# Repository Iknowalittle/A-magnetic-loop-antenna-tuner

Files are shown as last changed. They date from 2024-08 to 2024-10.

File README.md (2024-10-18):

This is a simple proto type magnetic loop antenna automatically tune project.
The code can be edit and build with Adunino.

There are somethings that I tried to implemented: 
  1) This stepper motor controller, after some search , finnaly I choose the motor driver chip TMC2209, It has the special function named "sensorless stall detection", which is definitely good 
for Vaccume capacitor because we have no good method to add the physical position limit sensor.
  2) The SWR meter. I use SI5351 act as the signal source and 2 AD8307 chips act as the forard and revese power meter to calculate the SWR.

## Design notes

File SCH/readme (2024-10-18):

open it wirh EAGLE 7.2 or later.
simple double side PCB

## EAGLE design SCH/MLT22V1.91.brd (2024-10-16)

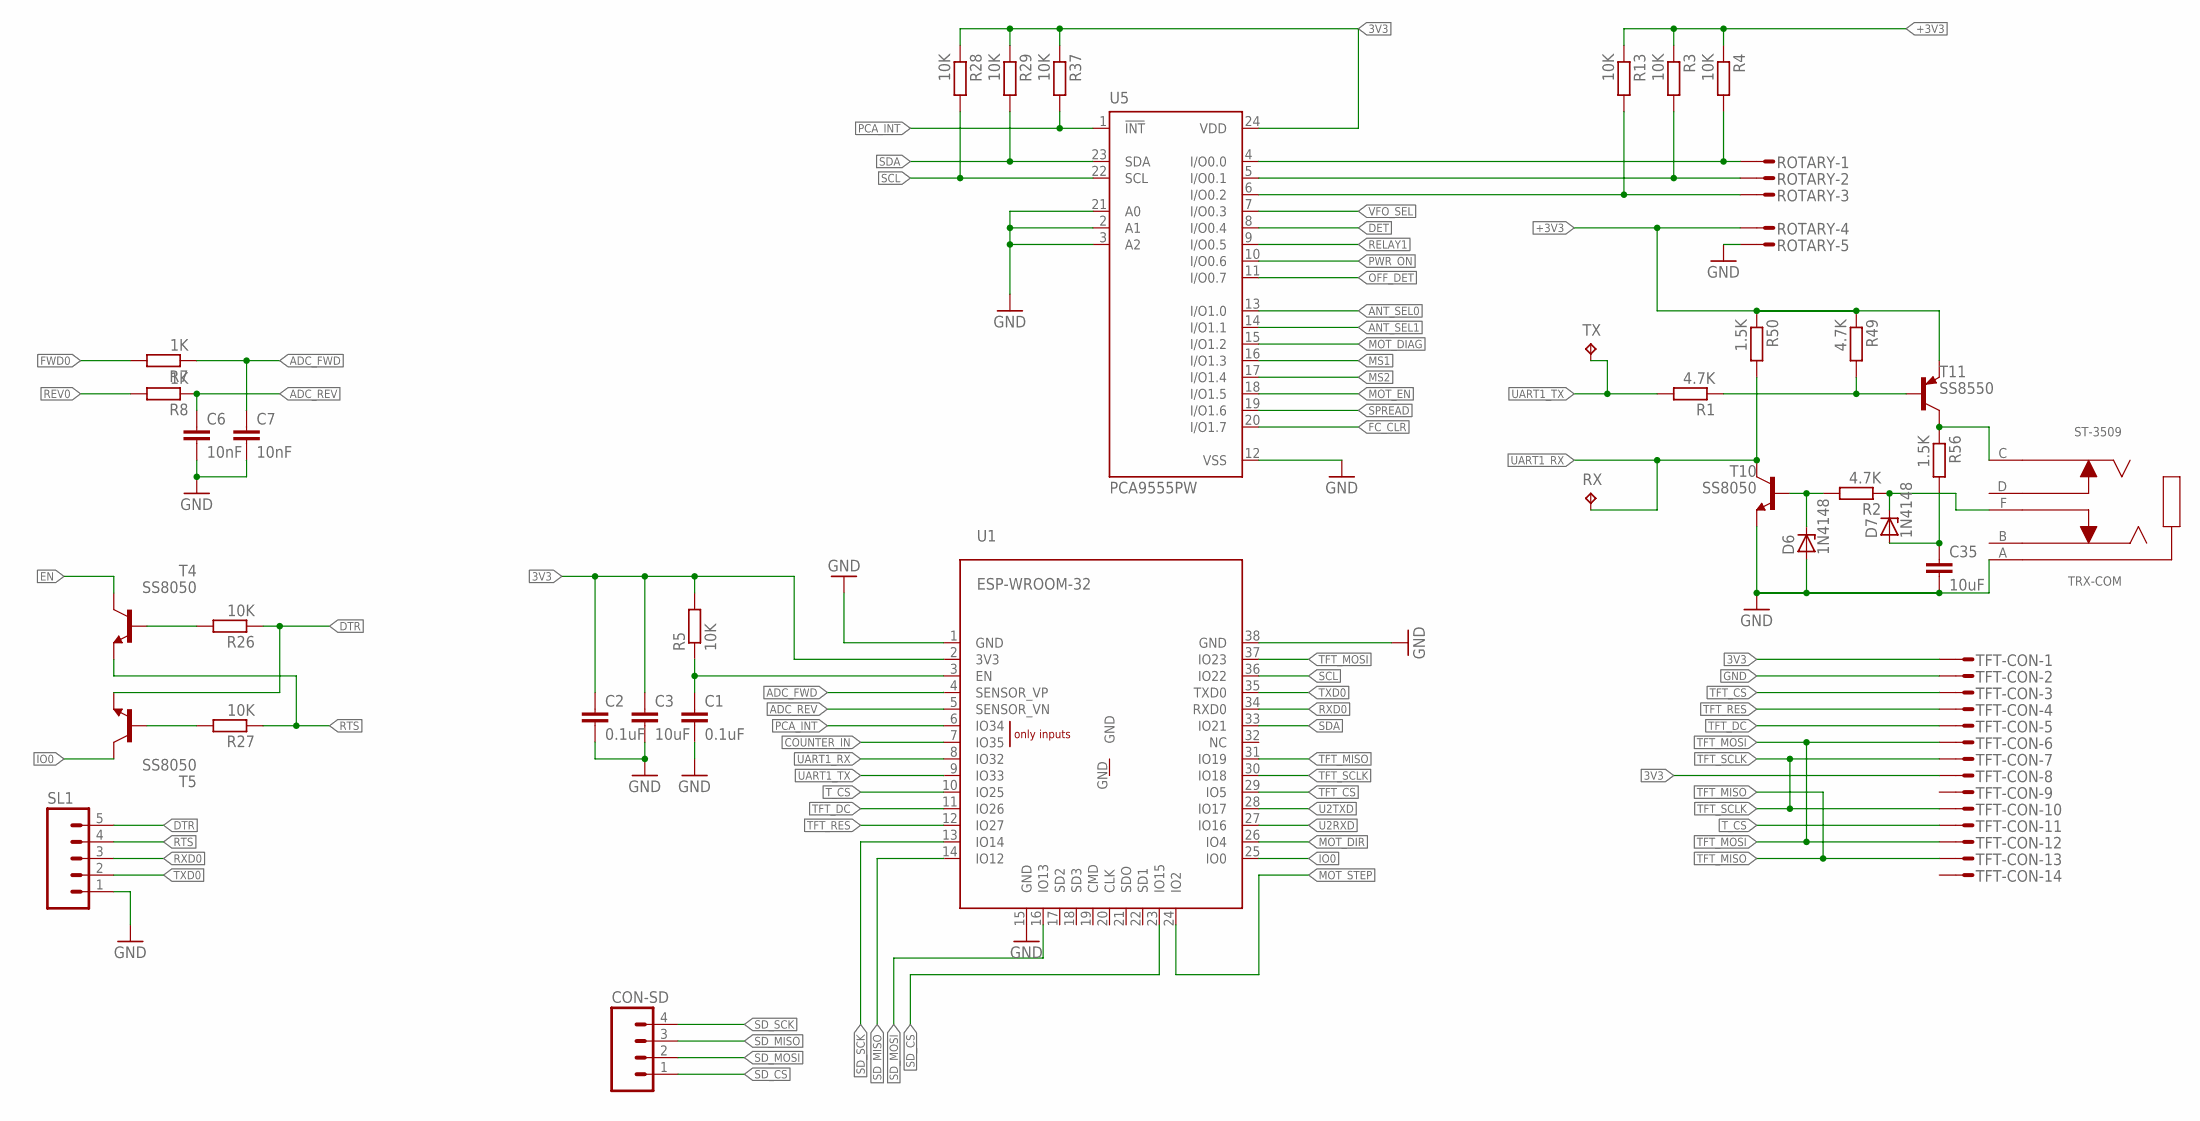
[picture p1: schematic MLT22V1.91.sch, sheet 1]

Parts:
C1, C2: 0.1uF; C0603
C3, C35: 10uF; C1206
C6, C7: 10nF; C0603
CON-SD: M04; 04P
D6, D7: 1N4148; SOD80C
R1, R2, R49: 4.7K; R0603
R3, R4, R5, R13, R26, R27, R28, R29, R37: 10K; R0603
R7, R8: 1K; R0603
R50, R56: 1.5K; R0603
ROTARY: S05P
RX: TPTP15R; TP15R
SL1: M05; 05P
T4, T5, T10: SS8050; SOT23-BEC
T11: SS8550; SOT23-BEC
TFT-CON: S14P
TRX-COM: ST-3509
TX: TPTP15R; TP15R
U1: ESP-WROOM-32
U5: PCA9555PW; TSSOP24

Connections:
3V3: C2.1, C3.1, R5.2, R28.1, R29.1, R37.1, TFT-CON.1, TFT-CON.8, U1.2 (3V3), U5.24 (VDD); also elsewhere on the board
+3V3: R3.1, R4.1, R13.1, R49.1, R50.1, ROTARY.4, T11.E; also elsewhere on the board
ADC_FWD: C7.1, R7.1, U1.4 (SENSOR_VP)
ADC_REV: C6.1, R8.1, U1.5 (SENSOR_VN)
ANT_SEL0: U5.13 (I/O1.0); also elsewhere on the board
ANT_SEL1: U5.14 (I/O1.1); also elsewhere on the board
COUNTER_IN: U1.7 (IO35); also elsewhere on the board
DET: U5.8 (I/O0.4); also elsewhere on the board
DTR: R26.1, SL1.5, T5.E
EN: C1.1, R5.1, T4.C, U1.3 (EN)
ENC_SW1: R3.2, ROTARY.2, U5.5 (I/O0.1)
ENC_SW2: R4.2, ROTARY.1, U5.4 (I/O0.0)
FC_CLR: U5.20 (I/O1.7); also elsewhere on the board
FWD0: R7.2; also elsewhere on the board
GND: C1.2, C2.2, C3.2, C6.2, C7.2, C35.2, D6.A, ROTARY.5, SL1.1, T10.E, TFT-CON.2, TRX-COM.A, U1.1 (GND), U1.15 (GND), U1.38 (GND), U5.2 (A1), U5.3 (A2), U5.12 (VSS), U5.21 (A0); also elsewhere on the board
IO0: T5.C, U1.25 (IO0)
MOT_DIAG: U5.15 (I/O1.2); also elsewhere on the board
MOT_DIR: U1.26 (IO4); also elsewhere on the board
MOT_EN: U5.18 (I/O1.5); also elsewhere on the board
MOT_STEP: U1.24 (IO2); also elsewhere on the board
MS1: U5.16 (I/O1.3); also elsewhere on the board
MS2: U5.17 (I/O1.4); also elsewhere on the board
unnamed: R56.1, T11.C, TRX-COM.C
unnamed: R13.2, ROTARY.3, U5.6 (I/O0.2)
unnamed: R1.1, R49.2, T11.B
unnamed: D6.C, R2.2, T10.B
unnamed: R26.2, T4.B
unnamed: R27.2, T5.B
unnamed: C35.1, D7.A, R56.2
unnamed: D7.C, R2.1, TRX-COM.F (E)
OFF_DET: U5.11 (I/O0.7); also elsewhere on the board
PCA_INT: R37.2, U1.6 (IO34), U5.1 (!INT)
PWR_ON: U5.10 (I/O0.6); also elsewhere on the board
RELAY1: U5.9 (I/O0.5); also elsewhere on the board
REV0: R8.2; also elsewhere on the board
RTS: R27.1, SL1.4, T4.E
RXD0: SL1.3, U1.34 (RXD0)
SCL: R28.2, U1.36 (IO22), U5.22 (SCL); also elsewhere on the board
SDA: R29.2, U1.33 (IO21), U5.23 (SDA); also elsewhere on the board
SD_CS: CON-SD.1, U1.23 (IO15)
SD_MISO: CON-SD.3, U1.14 (IO12)
SD_MOSI: CON-SD.2, U1.16 (IO13)
SD_SCK: CON-SD.4, U1.13 (IO14)
SPREAD: U5.19 (I/O1.6); also elsewhere on the board
TFT_CS: TFT-CON.3, U1.29 (IO5)
TFT_DC: TFT-CON.5, U1.11 (IO26)
TFT_MISO: TFT-CON.13, U1.31 (IO19)
TFT_MOSI: TFT-CON.6, TFT-CON.12, U1.37 (IO23)
TFT_RES: TFT-CON.4, U1.12 (IO27)
TFT_SCLK: TFT-CON.7, TFT-CON.10, U1.30 (IO18)
TXD0: SL1.2, U1.35 (TXD0)
T_CS: TFT-CON.11, U1.10 (IO25)
U2RXD: U1.27 (IO16); also elsewhere on the board
U2TXD: U1.28 (IO17); also elsewhere on the board
UART1_RX: R50.2, RX.TP, T10.C, U1.8 (IO32)
UART1_TX: R1.2, TX.TP, U1.9 (IO33)
VFO_SEL: U5.7 (I/O0.3); also elsewhere on the board

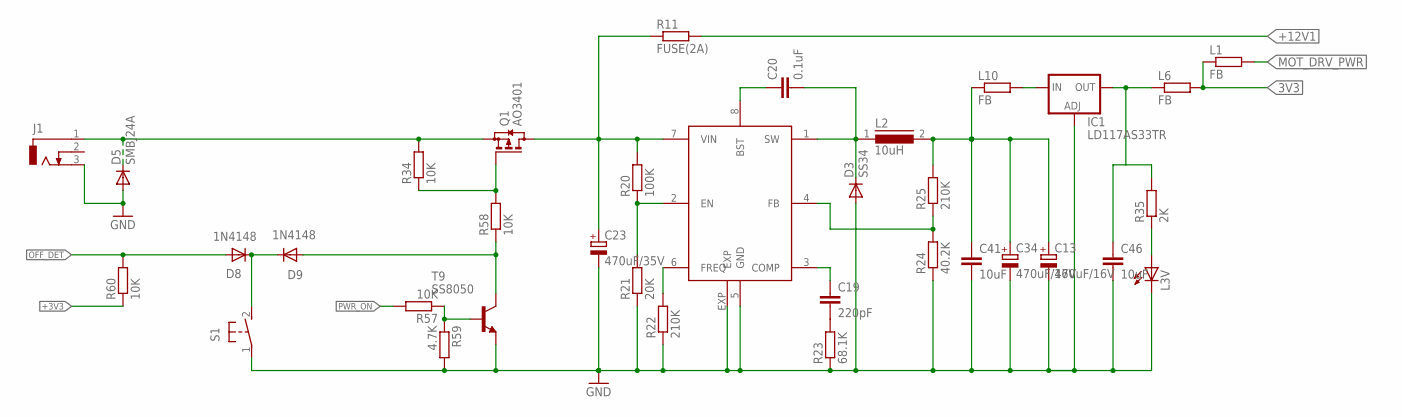
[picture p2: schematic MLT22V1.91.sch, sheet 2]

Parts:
C13, C34: 470uF/16V; 153CLV-0605
C19: 220pF; C0603
C20: 0.1uF; C0603
C23: 470uF/35V; 175TMP-0808
C41, C46: 10uF; C1206
D3: SS34; SMB
D5: SMBJ24A; SMB
D8, D9: 1N4148; SOD80C
IC1: LD117AS33TR; SOT223
J1: DCJ0303
L1, L6, L10: FB; R1206
L2: 10uH; DR74
L3V: LEDSML1206; SML1206
Q1: AO3401; SOT23
R11: FUSE(2A); R1206
R20: 100K; R0603
R21: 20K; R0603
R22, R25: 210K; R0603
R23: 68.1K; R0603
R24: 40.2K; R0603
R34, R57, R58, R60: 10K; R0603
R35: 2K; R0603
R59: 4.7K; R0603
S1: 31-XX; B3F-31XX
T9: SS8050; SOT23-BEC
U2: MP1584; SO-8P

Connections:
3V3: L1.1, L6.2; also elsewhere on the board
+3V3: C46.1, IC1.4 (OUT), L6.1, R35.2, R60.1; also elsewhere on the board
+5V: C13.+, C34.+, C41.1, L2.2, L10.1, R25.2; also elsewhere on the board
+12V1: R11.2; also elsewhere on the board
DCDC_BST2: C20.1, U2.8 (BST)
DCDC_COMP2: C19.1, U2.3 (COMP)
DCDC_EN2: R20.1, R21.2, U2.2 (EN)
DCDC_FB2: R24.2, R25.1, U2.4 (FB)
DCDC_SW2: C20.2, D3.C, L2.1, U2.1 (SW)
GND: C13.-, C23.-, C34.-, C41.2, C46.2, D3.A, D5.A, IC1.1 (ADJ), J1.3, L3V.C, R21.1, R22.1, R23.1, R24.1, R59.2, S1.1, T9.E, U2.5 (GND), U2.EXP; also elsewhere on the board
MOT_DRV_PWR: L1.2; also elsewhere on the board
unnamed: L3V.A, R35.1
unnamed: D5.C, J1.1, Q1.2 (S), R34.2
unnamed: C19.2, R23.2
unnamed: IC1.3 (IN), L10.2
unnamed: R22.2, U2.6 (FREQ)
unnamed: Q1.1 (G), R34.1, R58.2
unnamed: R57.1, R59.1, T9.B
unnamed: D8.C, D9.C, S1.2 (S)
unnamed: C23.+, Q1.3 (D), R11.1, R20.2, U2.7 (VIN)
OFF_DET: D8.A, R60.2; also elsewhere on the board
ONOFF: D9.A, R58.1, T9.C
PWR_ON: R57.2; also elsewhere on the board

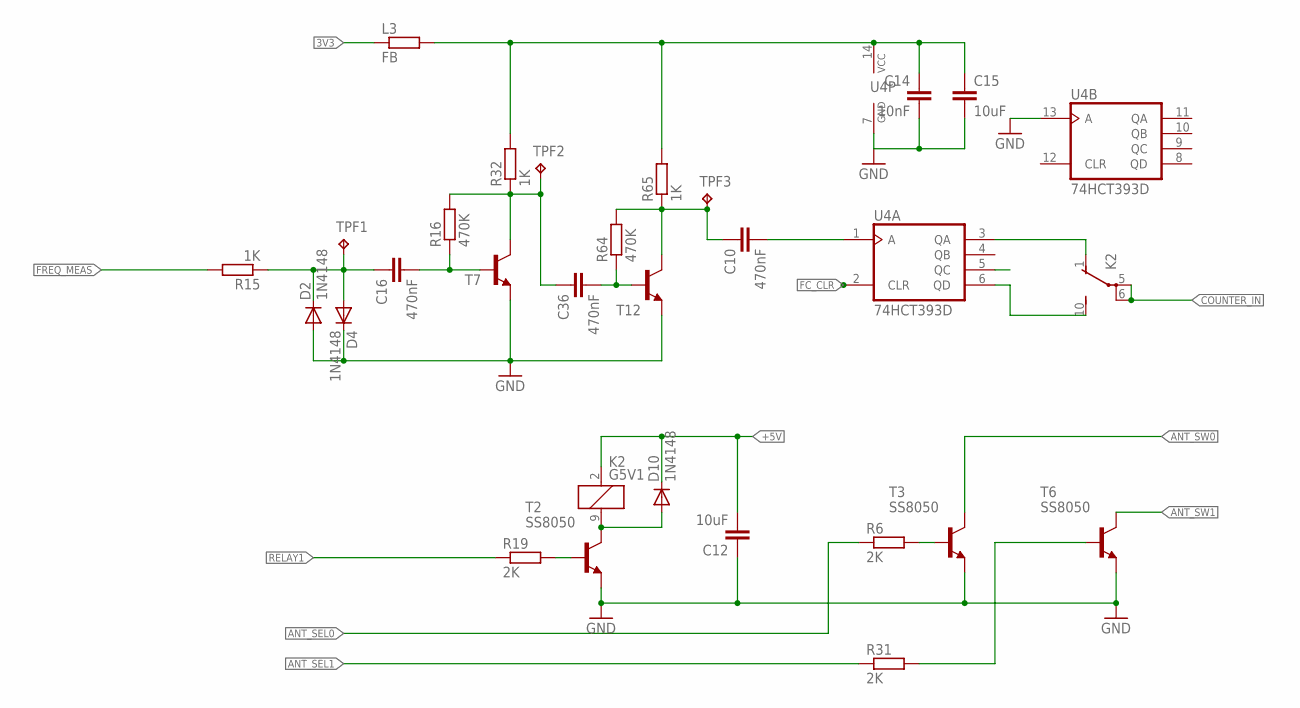
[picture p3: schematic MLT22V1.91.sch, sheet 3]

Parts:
C10, C16, C36: 470nF; C0603
C12, C15: 10uF; C1206
C14: 10nF; C0603
D2, D4, D10: 1N4148; SOD80C
K2: G5V1
L3: FB; R1206
R6, R19, R31: 2K; R0603
R15, R32, R65: 1K; R0603
R16, R64: 470K; R0603
T2, T3, T6: SS8050; SOT23-BEC
T7, T12: MMBT3904LT1-NPN-SOT23-BEC; SOT23-BEC
TPF1, TPF2, TPF3: TPTP15R; TP15R
U4: 74HCT393D; SO14

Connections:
3V3: L3.1; also elsewhere on the board
3V3_F: C14.1, C15.1, L3.2, R32.2, R65.2, U4.14 (VCC); also elsewhere on the board
+5V: C12.2, D10.C, K2.2 (1); also elsewhere on the board
ANT_SEL0: R6.1; also elsewhere on the board
ANT_SEL1: R31.1; also elsewhere on the board
ANT_SW0: T3.C; also elsewhere on the board
ANT_SW1: T6.C; also elsewhere on the board
COUNTER_IN: K2.5, K2.6; also elsewhere on the board
FC_CLR: U4.2 (CLR); also elsewhere on the board
FREQIN0: C36.1, R16.2, R32.1, T7.C, TPF2.TP
FREQIN1: C10.1, R64.2, R65.1, T12.C, TPF3.TP
FREQ_BY_16: K2.10 (S), U4.6 (QD)
FREQ_MEAS: R15.2; also elsewhere on the board
GND: C12.1, C14.2, C15.2, D2.A, D4.C, T2.E, T3.E, T6.E, T7.E, T12.E, U4.7 (GND), U4.13 (A); also elsewhere on the board
unnamed: C10.2, U4.1 (A)
unnamed: K2.1 (O), U4.3 (QA)
unnamed: R6.2, T3.B
unnamed: C16.1, D2.C, D4.A, R15.1, TPF1.TP
unnamed: D10.A, K2.9 (2), T2.C
unnamed: R19.2, T2.B
unnamed: R31.2, T6.B
unnamed: C16.2, R16.1, T7.B
unnamed: C36.2, R64.1, T12.B
RELAY1: R19.1; also elsewhere on the board

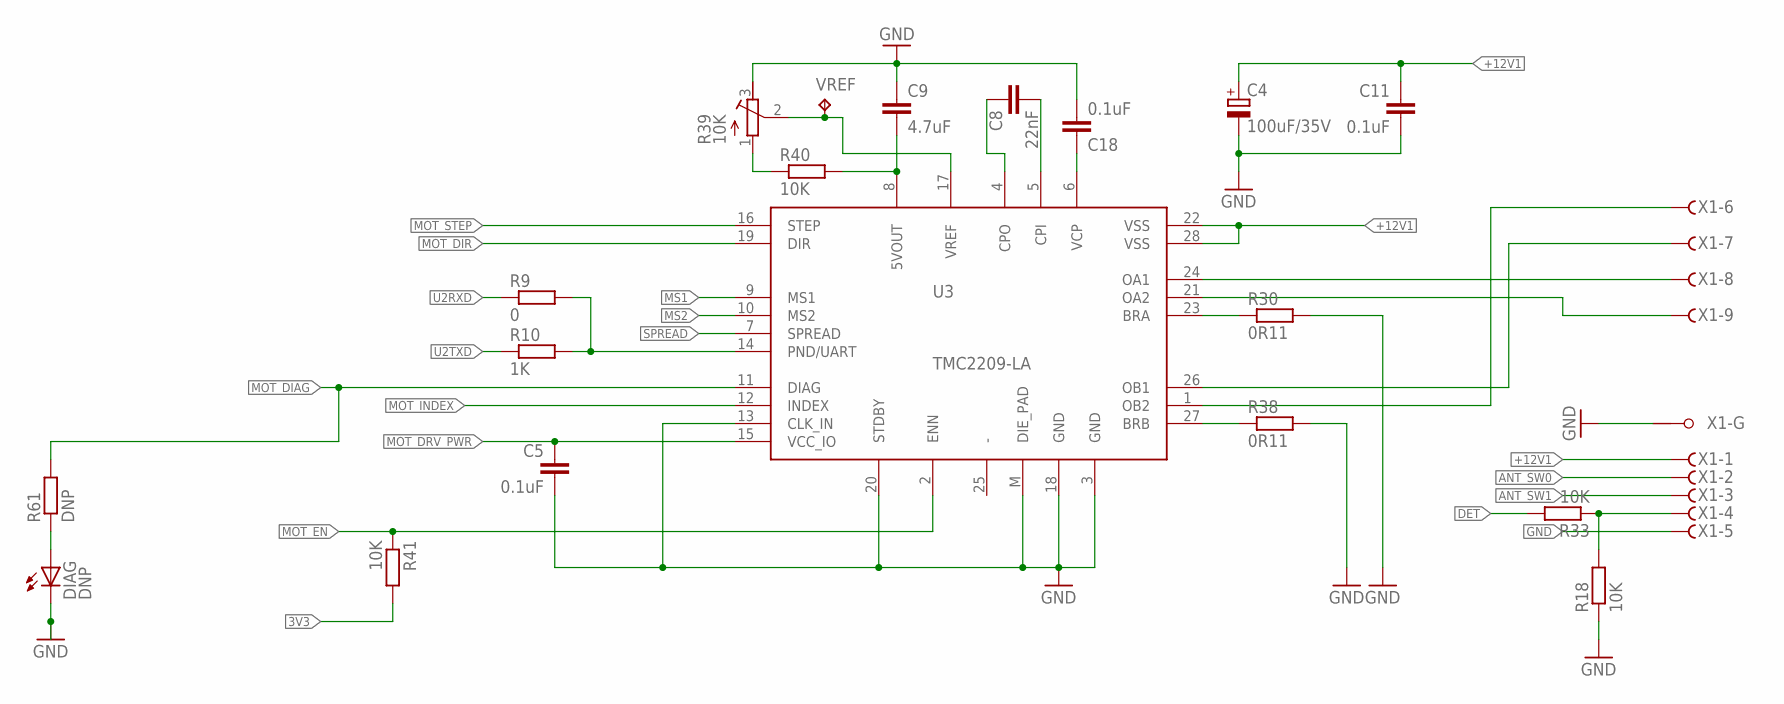
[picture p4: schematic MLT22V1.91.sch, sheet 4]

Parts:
C4: 100uF/35V; 150CLZ-1010
C5, C11, C18: 0.1uF; C0603
C8: 22nF; C0603
C9: 4.7uF; C1206
DIAG: DNP; SML1206
R9: 0; R0603
R10: 1K; R0603
R18, R33, R40, R41: 10K; R0603
R30, R38: 0R11; R1206
R39: 10K; RTRIM3103
R61: DNP; R0603
U3: TMC2209-LA; QFN28
VREF: TPB1,27; B1,27
X1: F09HPS; F09HP

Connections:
3V3: R41.2; also elsewhere on the board
5VOUT: C9.2, R40.2, U3.8 (5VOUT)
+12V1: C4.+, C11.1, U3.22 (VSS), U3.28 (VSS), X1.1 (F); also elsewhere on the board
ANT_SW0: X1.2 (F); also elsewhere on the board
ANT_SW1: X1.3 (F); also elsewhere on the board
BRA: R30.1, U3.23 (BRA)
BRB: R38.1, U3.27 (BRB)
CPI: C8.2, U3.5 (CPI)
CPO: C8.1, U3.4 (CPO)
DET: R33.2; also elsewhere on the board
GND: C4.-, C5.2, C9.1, C11.2, C18.2, DIAG.C, R18.1, R30.2, R38.2, R39.3 (E), U3.3 (GND), U3.13 (CLK_IN), U3.18 (GND), U3.20 (STDBY), U3.M (DIE_PAD), X1.5 (F), X1.G1; also elsewhere on the board
MOT_DIAG: R61.2, U3.11 (DIAG); also elsewhere on the board
MOT_DIR: U3.19 (DIR); also elsewhere on the board
MOT_DRV_PWR: C5.1, U3.15 (VCC_IO); also elsewhere on the board
MOT_EN: R41.1, U3.2 (ENN); also elsewhere on the board
MOT_INDEX: U3.12 (INDEX)
MOT_STEP: U3.16 (STEP); also elsewhere on the board
MS1: U3.9 (MS1); also elsewhere on the board
MS2: U3.10 (MS2); also elsewhere on the board
unnamed: DIAG.A, R61.1
unnamed: R39.1 (A), R40.1
unnamed: R18.2, R33.1, X1.4 (F)
OA1: U3.24 (OA1), X1.8 (F)
OA2: U3.21 (OA2), X1.9 (F)
OB1: U3.26 (OB1), X1.7 (F)
OB2: U3.1 (OB2), X1.6 (F)
PD/UART: R9.2, R10.2, U3.14 (PND/UART)
SPREAD: U3.7 (SPREAD); also elsewhere on the board
U2RXD: R9.1; also elsewhere on the board
U2TXD: R10.1; also elsewhere on the board
VCP: C18.1, U3.6 (VCP)
VREF: R39.2 (S), U3.17 (VREF), VREF.TP

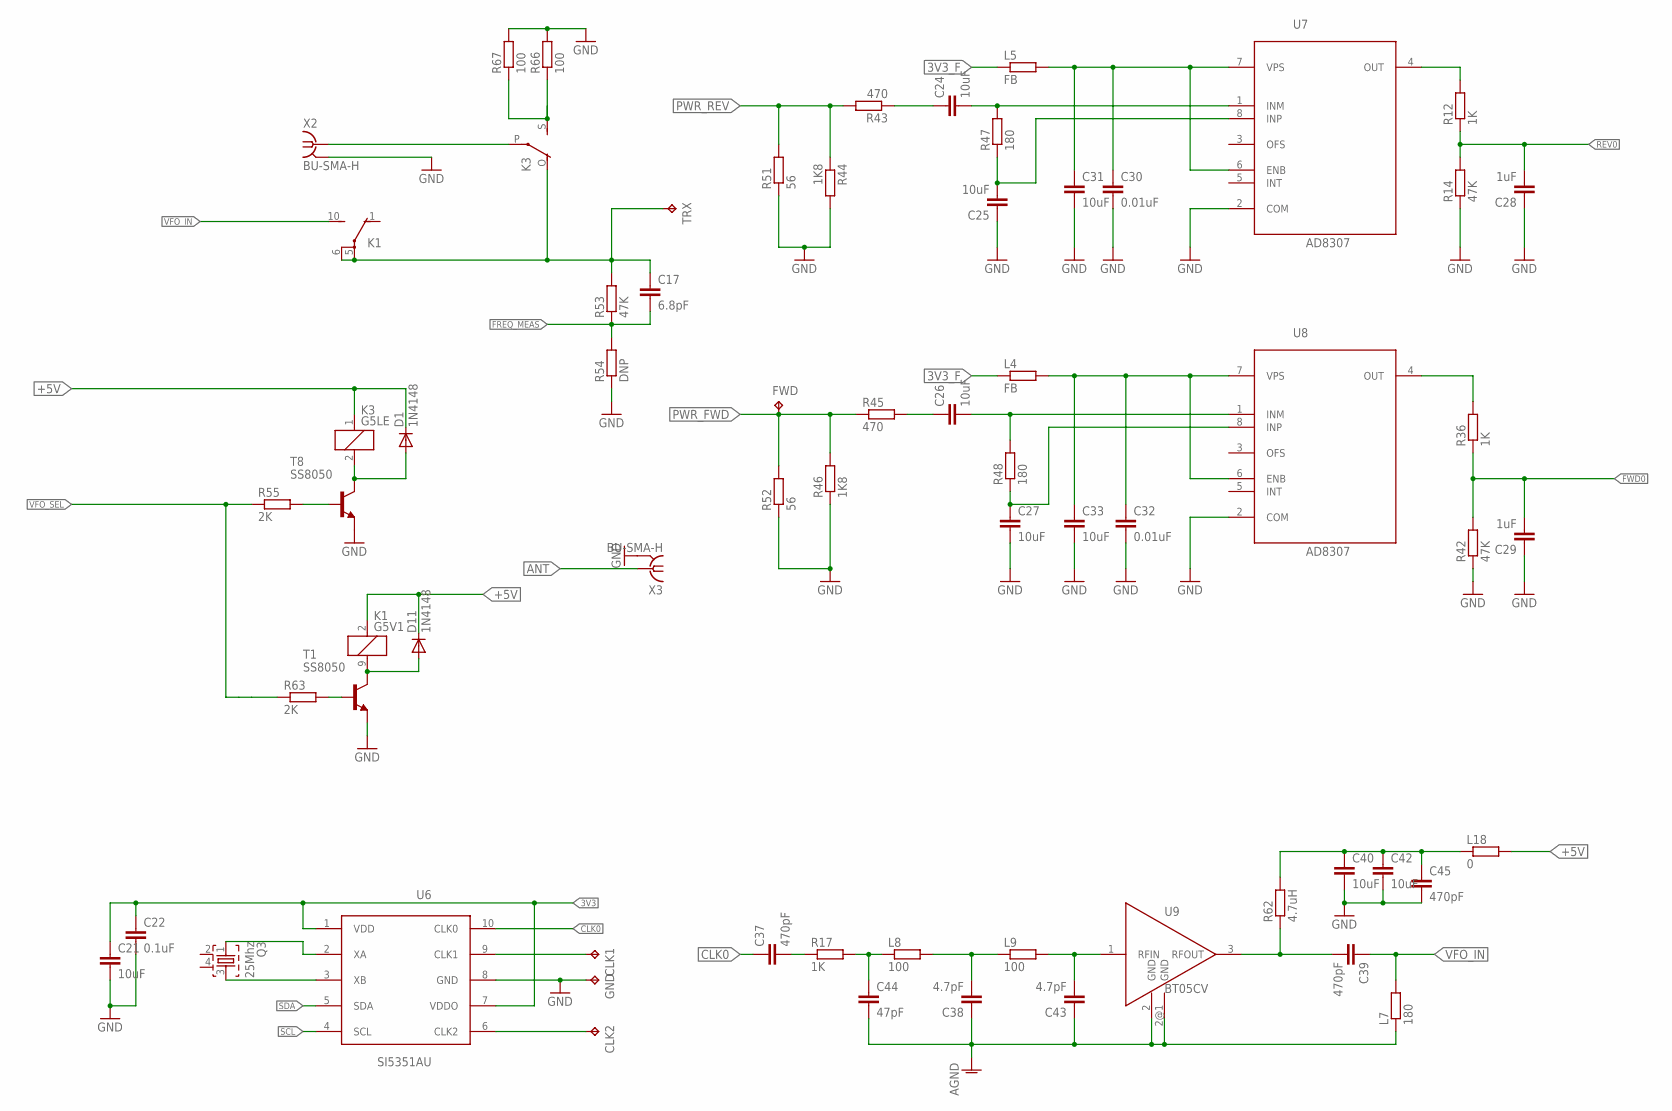
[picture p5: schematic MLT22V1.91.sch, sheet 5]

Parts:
C17: 6.8pF; C0603
C21, C24, C25, C26, C27, C31, C33, C40, C42: 10uF; C1206
C22: 0.1uF; C0603
C28, C29: 1uF; C0603
C30, C32: 0.01uF; C0603
C37, C45: 470pF; C0603
C38, C43: 4.7pF; C0603
C39: 470pF; C0805
C44: 47pF; C0603
CLK1, CLK2: TPTP15R; TP15R
D1, D11: 1N4148; SOD80C
FWD: TPPAD1-20; P1-20
GND: TPTP15R; TP15R
K1: G5V1
K3: G5LE
L4, L5: FB; R1206
L7: 180; R0603
L8, L9: 100; R0603
L18: 0; R1206
Q3: 25Mhz; SMD3225
R12, R17, R36: 1K; R0603
R14, R42, R53: 47K; R0603
R43, R45: 470; R1206
R44, R46: 1K8; R1206
R47, R48: 180; R0603
R51, R52: 56; 0922/22
R54: DNP; R0603
R55, R63: 2K; R0603
R62: 4.7uH; R0805
R66, R67: 100; 0922/22
T1, T8: SS8050; SOT23-BEC
TRX: TPPAD1-20; P1-20
U6: SI5351AU; MSOP10
U7, U8: AD8307; SO08
U9: BT05CV; SOT89
X2, X3: BU-SMA-H

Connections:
3V3: C21.1, C22.1, U6.1 (VDD), U6.7 (VDDO); also elsewhere on the board
3V3_F: L4.1, L5.1; also elsewhere on the board
+5V: D1.C, D11.C, K1.2 (1), K3.1, L18.2; also elsewhere on the board
ANT: X3.1
CLK0: C37.1, U6.10 (CLK0)
CLK1: CLK1.TP, U6.9 (CLK1)
CLK2: CLK2.TP, U6.6 (CLK2)
FREQ_MEAS: C17.2, R53.1, R54.2; also elsewhere on the board
FWD0: C29.2, R36.1, R42.2; also elsewhere on the board
GND: C21.2, C22.2, C25.1, C27.2, C28.1, C29.1, C30.2, C31.2, C32.2, C33.2, C38.1, C40.2, C42.2, C43.1, C44.2, C45.2, GND.TP, L7.1, R14.1, R42.1, R44.2, R46.1, R51.1, R52.1, R54.1, R66.2, R67.2, T1.E, T8.E, U6.8 (GND), U7.2 (COM), U8.2 (COM), U9.2 (GND), U9.2@1 (GND), X2.2, X2.3 (2), X2.4 (2), X2.5 (2), X3.2, X3.3 (2), X3.4 (2), X3.5 (2); also elsewhere on the board
unnamed: C24.2, R47.2, U7.1 (INM)
unnamed: C25.2, R47.1, U7.8 (INP)
unnamed: C24.1, R43.1
unnamed: C30.1, C31.1, L5.2, U7.6 (ENB), U7.7 (VPS)
unnamed: R12.2, U7.4 (OUT)
unnamed: R55.2, T8.B
unnamed: C32.1, C33.1, L4.2, U8.6 (ENB), U8.7 (VPS)
unnamed: D1.A, K3.2, T8.C
unnamed: K3.S, R66.1, R67.1
unnamed: C27.1, R48.1, U8.8 (INP)
unnamed: C26.2, R48.2, U8.1 (INM)
unnamed: C26.1, R45.2
unnamed: R36.2, U8.4 (OUT)
unnamed: Q3.1, U6.2 (XA)
unnamed: Q3.3, U6.3 (XB)
unnamed: C38.2, L8.2, L9.1
unnamed: C43.2, L9.2, U9.1 (RFIN)
unnamed: C39.2, R62.1, U9.3 (RFOUT)
unnamed: D11.A, K1.9 (2), T1.C
unnamed: R63.2, T1.B
unnamed: C37.2, R17.1
unnamed: C44.1, L8.1, R17.2
PA3V: C40.1, C42.1, C45.1, L18.1, R62.2
PWR_FWD: FWD.TP, R45.1, R46.2, R52.2
PWR_REV: R43.2, R44.1, R51.2
REV0: C28.2, R12.1, R14.2; also elsewhere on the board
SCL: U6.4 (SCL); also elsewhere on the board
SDA: U6.5 (SDA); also elsewhere on the board
TRX: C17.1, K1.5, K1.6, K3.O, R53.2, TRX.TP
TRX_IN: K3.P, X2.1
VFO_IN: C39.1, K1.10 (S), L7.2
VFO_SEL: R55.1, R63.1; also elsewhere on the board

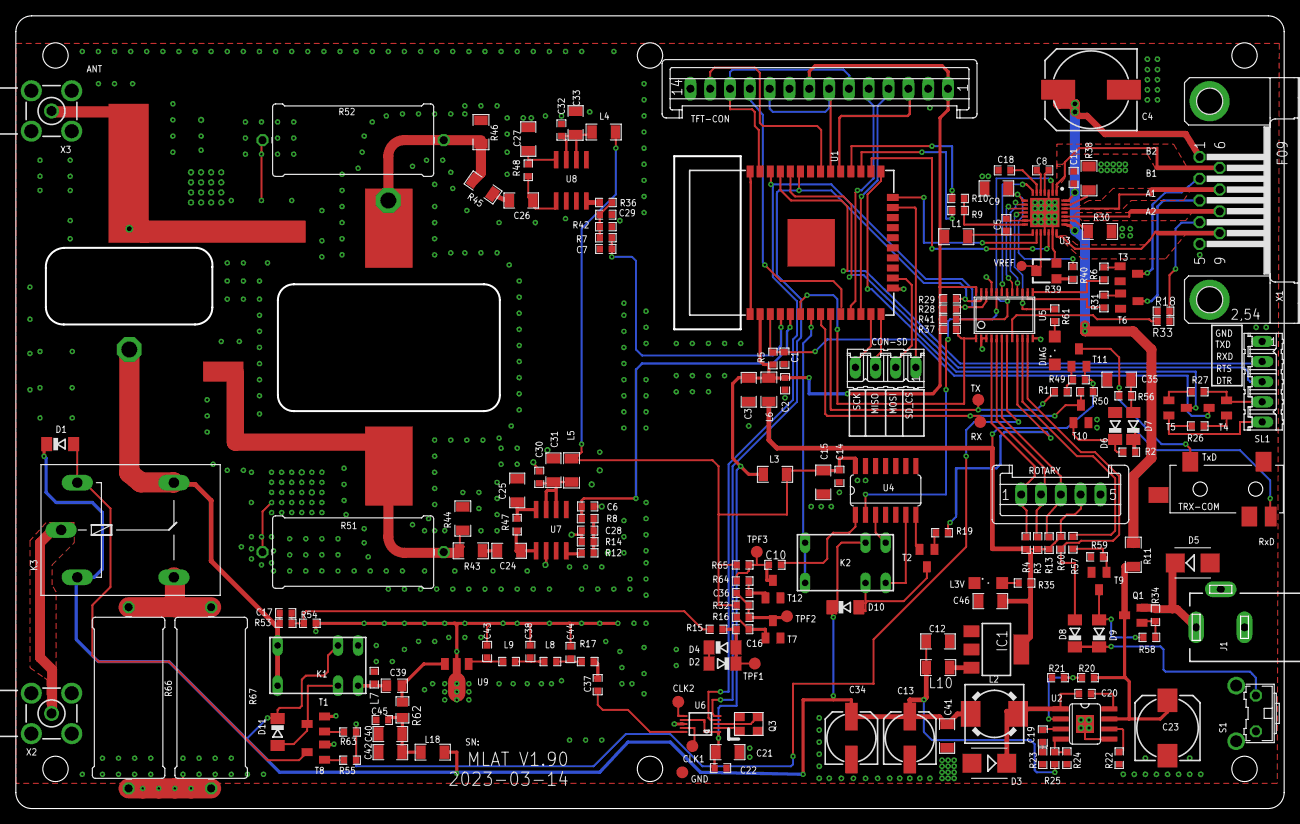
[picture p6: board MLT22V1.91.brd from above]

Board: 2 copper layers, 160.0 x 100.0 mm, 185 parts (0 on the bottom side), 137 nets.

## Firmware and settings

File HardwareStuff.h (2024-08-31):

#include <sys/_stdint.h>
#ifndef MLAT22_HW_STUFF_HEADER
#define MLAT22_HW_STUFF_HEADER

 

#include <Ticker.h>            
#include "AntennaParaMgr.h"
                 
#include  "soc/pcnt_struct.h"
#include "driver/pcnt.h"  // ESP32 library for pulse count




#define UART1_TX    33
#define UART1_RX    32

#define DEFAULT_MOTOR_CURRENT   1500
#define DEFAULT_MOTOR_STALL_TH  150
#define DEFAULT_MOTOR_MICROSTEP 2
#define DEFAULT_MOTOR_FINESTEP  8
#define DEFAULT_MOTOT_INT_TIME  800

typedef enum MOT_STEP_MODE_DEF
{
   MOT_0_0_OFF=0,
   MOT_1_1_STEP ,        //Full
   MOT_1_2_STEP ,          //Half
   MOT_1_4_STEP ,          //Quater
   MOT_1_8_STEP ,          //Eighth
   MOT_1_16_STEP ,          //Sixteenth
   MOT_1_32_STEP ,          //Sixteenth
   MOT_1_64_STEP ,          //Sixteenth
   MOT_1_128_STEP ,          //Sixteenth
   MOT_1_256_STEP           //Sixteenth
}MOT_MAN_MODE;

MOT_MAN_MODE Current_MOT_MODE;

typedef enum 
{
    MT_COUNTER_MODE=0,
    MT_SWR_MODE=1  
}MOTOR_TASK;
//tune mode 
/*
  1) in steps
  2) seeking minimum swr for current frequency.

*/
typedef struct _MotorRunningMsg_
{
    //just do step pin puls
    MOTOR_TASK TaskMode;     
    union Parameters 
    {
      struct 
      {
        int32_t Steps2Run;
        int32_t StepsPulsed;
        int32_t DelayTimes;		//min delay time in microseconds.
      }CounterModes;
      struct  
      {
        uint16_t SwrInterval;  
        uint16_t min_swr_tuned;        //X10
        float   SWRTarget;  
        int32_t PresetPositon;
      }SWRModes;
    }TaskParameters;
    int32_t DelayTimes;		//min delay time in microseconds.
    bool Running;     
    bool EnableTask;
    bool ExitService;
    bool TuneOK;
}MotorRunningMsg;

void rotary_onButtonClick();
void SetupRotaryEncoder();
void EncoderTask();
void RotaryModeProcess();

//Stepper Motor related 
void StartMotorService(void);
void MotorTaskRunner(void *parameter);

void SetupStepperMotor();

void ConfigStepperMicroStep(uint8_t steps);

void MotorEnControl(bool Enable);
void UpdateMotorStepperSetting();
bool MoveToLimitPosition(int8_t direction,uint32_t * TotalSteps,int32_t MinRunningSteps=-1);

bool FindHomePosition(uint32_t *TotalSteps0,uint32_t *TotalSteps1);

bool FindMovingRanges();

void MoveMotorInSteps0(int32_t steps,uint32_t delayInMicroSeconds);
uint32_t MoveMotorInSteps(int32_t steps,uint32_t delayInMicroSeconds);
//bool FindBestSWR(float BFOFrequency);
bool FindBestSWR(float BFOFrequency,uint32_t presetpos,uint16_t &swr_v);
bool SeekPosForFreq(uint32_t freq);

bool Move2RightPositionByFreq(uint32_t freq);

//float SWRMeasureAndDelay(uint32_t MaxDelayTimesInUs);
void SetMotorTask(int32_t steps,uint32_t delayInMicroSeconds);
void SetMotorSWRModeTask(uint32_t presetPos,uint32_t delayInMicorSeconds);

void MotorSWRModeProcess(MotorRunningMsg *ThreadMsg);
void MotorCounterModeProcess(MotorRunningMsg *ThreadMsg);
void MotorTaskProcess(MotorRunningMsg *ThreadMsg);
uint32_t MoveMotors(int32_t StepsInCount,int8_t SeekingDir, uint16_t SWR_interval, float * p_min_swr_value);
//bool MotorConnected();
void SetMotorDir(uint8_t dir);

void SetTOff(uint8_t t_Off);
void SetMotorRefSource(bool UseExternal);

uint8_t ReadMotorDiagFlag();
void ConfigStepperAddress(uint8_t addr);
void MotorSpreadControl(bool Mode);
uint32_t MotorMicroSteps();
void PulseMotorSteps();
void SetStallTH(uint8_t v);
void SetMotorCurrent(uint16_t rms_max);
void AbortMotorTask();
void ShowMotorDriverStatus();
void SetMotorSpeed(uint32_t speed);
void UpdateMotorProgress(uint8_t val);
void UpdateMotorPosition(bool save=false);


//Frequency Generator
void SelectFrequencyChan(uint8_t src);
bool SetupFrequencyGenerator();
int SetFG_Frequency(uint64_t Freq);
int SetFG_Level(uint8_t Level);  
void TurnFGOn();
void TurnFGOff();

//Frequency Counter
typedef enum FC_CHANNEL_DEF
{
  FC_CHAN_X1=0,
  FC_CHAN_X4,
  FC_CHAN_X16
}FC_CHAN_DEF;
void      SetupFreqTimer();
int32_t   Read_Reset_PCNT();
int      SelectFreqChan(FC_CHAN_DEF chan);      //0: basic ch <15M....   1:    /4  
float     GetAndCheckFreq();
void      UpdateFrequencyCounter();
void      ClearFreqCounter();


void Switch2TRXChan();
void Switch2BFOChan();

//SWR meter
float dbm2mW(float dbmIn);

void SetupSWRMeter();
float GetFWDValue();
float GetREVValue();
float GetSWRValue(uint8_t AvgCount,float *fwd,float *rev,bool dbmMode=true);
float GetSWRValueAvg(uint8_t AvgCount,float *fwd,float *rev,bool dbmMode=true);

void UpdateSWRMeter();
void ResetSWR();
void SWREva(uint8_t buffer_size,uint8_t delta);

uint16_t SWRADCRead(uint16_t count,float *fwd,float *rev);
uint16_t SWRADCReadAVG(uint16_t count,float *fwd,float *rev);

int CountingArray(float  *array,float *MainV,uint16_t size,float delta,bool showDetail=false);
void RefreshSWRMeter(float swr,float fwd, float rev);
bool CheckSWRTune(float SWRThreshold,float &swr_actual);

//plotter related
void swrfindChartInit();
//void swrfindAddPoint(uint32_t step,float swr);
                      
//Serial command process
void SerialTask();
//OTA related;
//==========================
// read default SSID and PSK
//==========================
// so user can do OTA update
// 
int LoadOTASetting(String& ssid,String& psk);
int SaveOTASetting(String ssid,String psk);


 //===system power control=========
 void IntializeIOEX();
 void ProcessIOEXEvent(bool firstread=false);
 void MaintainPowerOn();
 void SwitchPowerOff();
 void IOEXWrite(uint8_t bit,uint8_t dat);
uint16_t IOEXRead(uint8_t Bit);
void ProcessIOTask();

void ProcessWiFiTask();
void WebPolling();
void WifiInit();
void RefreshWifiList();
bool WiFiTryConnect(char *ssid,char *password);
bool IsWiFiConnected();
String GetIpAddress();

void DoWebUpdate();
void setupTelnet();
void ProcessTelnetCommand(String strcmd);

void PageShow(uint16_t pageid);   // stack it.
void PageHide(uint16_t pageid);

void ShowBusyBox();
void RefreshBusyBox();
void HideBusyBox();

void Add2UIFreqList(uint32_t freq);
void Add2UIWifiList(const char *ssid,int32_t rssi);
void Add2UIRadioList(const char *RadioType);

void SelectFreqItem(int16_t nID);
void SelectTRXItem(int16_t nID);
void SelectWifiItem(int16_t nID);

void InitializeRadioList();
void ResetRadioListBox();  //void gslc_ElemXListboxReset(gslc_tsGui* pGui, gslc_tsElemRef* pElemRef);
void ResetWifiListBox();
void ResetFreqListBox();

void ShowTipMsg(const char *msg);
void UpdateIpAddr(const char *ipaddr,bool Valid=false);
void ShowPageID(const char *id);
void ShowWifiSSID(const char *ssid);
void SetChartTitle(const char *title);

void ShowPresetFreqList();

void UpdateFreqSource(uint8_t src);
void RemovePresetFreq();
void Config2SwrMode();
void DoOTAUpgrade();
#endif

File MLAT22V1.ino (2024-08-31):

//<App !Start!>
// FILE: [Arduino.ino]
// Created by GUIslice Builder version: [0.17.b12]
//
// GUIslice Builder Generated File
//
// For the latest guides, updates and support view:
// https://github.com/ImpulseAdventure/GUIslice
//
//<App !End!>
#include "HardwareStuff.h"
#include "MovingAverage.h"
#include "MLAT22.h"
#include "AntennaParaMgr.h"
#include <FS.h>
#include <SPIFFS.h>
#include <TMCStepper.h>
#include "MLAT22UI_GSLC.h"
#include <TFT_eSPI.h>
#include "RotaryEncoder.h"
#include "ChartPlotter.h"
#include "ShortWaveBands.h"
#include "ESPTelnet.h"
#include <vector>
extern ESPTelnet telnet;
extern bool TelnetConnected;
extern volatile uint32_t ActiveFrequency;
extern bool UseInternalClkSrc;

bool OTAModeEnabled = false;
bool TelnetEnabled = false;
bool TrxSignalExists = false;
uint8_t clk_src = 0;
bool MsgBoxOK=false;
char MsgBoxBuffer[512];
//String inputString = "";          // a String to hold incoming data
enum CMD_SOURCE {
  NO_COMMAND = 0,
  SERIAL_INPUT = 1,
  TELNET_INPUT = 2,
  UICMD_INPUT,
};
CMD_SOURCE StringCommandInput = NO_COMMAND;  // whether the string is complete

bool Taskrunning = false;

#define MAX_MSG_LENGTH 250
uint16_t current_rx_ptr = 0;
char rx_buffer[MAX_MSG_LENGTH];

extern MOT_MAN_MODE Current_MOT_MODE;
extern MotorRunningMsg MotorMsg;  // for service mode task.
extern volatile uint8_t MotorEnabled;

extern TMC2209Stepper MotorDriver;

uint16_t OldStallDetected = 0;
uint16_t StallCount = 0;
uint16_t old_busy_prg_val = 0;  // busy box indicator
uint32_t tmr_watch_count;       //timer watch for finding motor home position progress
int16_t TrxSelected, FreqSelected, WiFiSelected;

uint32_t MaxMotorMoveSteps = 0;
int32_t CurrentMotorPosition = 0;
int8_t MotorDir;
uint32_t CurrentSelectedFrequency = 0;
std::vector<uint16_t> PageStacks;
AuxRotEncoder rotaryEncoder;
ExtButton PowerOffKey;

LineChart mChart;
float FreqDetected;
#define PRESET_FREQ_PER_PAGE 4

uint16_t MaxPresetFreqs = 0;
uint16_t MaxPresetPages = 0;
uint16_t CurrentPresetPage;
//extern ESP_FlexyStepper stepper;
//unsigned    m_nCount = 0;
extern volatile uint16_t ioex_int_flag;
extern volatile uint8_t MotorStallFlag;
// move to antenna
MotorInformationDef MotorRunningConfig;
SWR_METER_OFFSET SWRMeterParas;
bool SwrMeterMode = false;
bool WifiInformationValid = false;

String PageID = "";  //user defined PageID. which can be displayed on the up right corner of Main UI
// record last actived Antenna and Position.
PositionInfomation OldAntennaPosInfo;

AntennaParaManager ML_ANT[4];  //support 4 antenna max.
float Freq_Delta[2]={0,0};
float FREF_Set[2]={0,0};
float FCorr_K=0,FCorr_B=0;
FREQ_CAL_OFFSET FreqCalPara;
float old_disp_freq=0.0f;
uint32_t  theTickOfBoot=0;
uint32_t  theMinOfBoot=0;
uint32_t  theSecOfBoot=0;
uint32_t  theHoursOfBoot=0;
// ------------------------------------------------
// Headers to include
// ------------------------------------------------



// ------------------------------------------------
// Program Globals
// ------------------------------------------------

// Save some element references for direct access
//<Save_References !Start!>
gslc_tsElemRef* m_eleSWRFWD = NULL;
gslc_tsElemRef* m_eleSWRREV = NULL;
gslc_tsElemRef* m_ele_ANTID116 = NULL;
gslc_tsElemRef* m_ele_BTN_TRX115 = NULL;
gslc_tsElemRef* m_ele_SWR = NULL;
gslc_tsElemRef* m_ele_TRXFreq = NULL;
gslc_tsElemRef* m_pElemANTC0 = NULL;
gslc_tsElemRef* m_pElemANTC1 = NULL;
gslc_tsElemRef* m_pElemANTC2 = NULL;
gslc_tsElemRef* m_pElemAddFreq = NULL;
gslc_tsElemRef* m_pElemAntIndex = NULL;
gslc_tsElemRef* m_pElemAntPage1 = NULL;
gslc_tsElemRef* m_pElemAntPage2 = NULL;
gslc_tsElemRef* m_pElemAntPage3 = NULL;
gslc_tsElemRef* m_pElemBand = NULL;
gslc_tsElemRef* m_pElemBandMeter = NULL;
gslc_tsElemRef* m_pElemBtn72 = NULL;
gslc_tsElemRef* m_pElemBtn72_125 = NULL;
gslc_tsElemRef* m_pElemBtn72_139 = NULL;
gslc_tsElemRef* m_pElemBtnBFO = NULL;
gslc_tsElemRef* m_pElemBtnBFOCH1 = NULL;
gslc_tsElemRef* m_pElemBtnBFOCH2 = NULL;
gslc_tsElemRef* m_pElemBtnMenu = NULL;
gslc_tsElemRef* m_pElemCBCheckBox = NULL;
gslc_tsElemRef* m_pElemChartTitle = NULL;
gslc_tsElemRef* m_pElemCurrentPos = NULL;
gslc_tsElemRef* m_pElemFWDUnit = NULL;
gslc_tsElemRef* m_pElemFreqSrc = NULL;
gslc_tsElemRef* m_pElemFstep = NULL;
gslc_tsElemRef* m_pElemFstep214 = NULL;
gslc_tsElemRef* m_pElemGraph_FreqScan = NULL;
gslc_tsElemRef* m_pElemIPAddr0 = NULL;
gslc_tsElemRef* m_pElemLinkTest = NULL;
gslc_tsElemRef* m_pElemListbox1_3 = NULL;
gslc_tsElemRef* m_pElemListboxFreq = NULL;
gslc_tsElemRef* m_pElemListboxWifi = NULL;
gslc_tsElemRef* m_pElemMsgBoxText = NULL;
gslc_tsElemRef* m_pElemNextPage = NULL;
gslc_tsElemRef* m_pElemOTA129 = NULL;
gslc_tsElemRef* m_pElemOTA129_136 = NULL;
gslc_tsElemRef* m_pElemOldTRX = NULL;
gslc_tsElemRef* m_pElemOutTxt185 = NULL;
gslc_tsElemRef* m_pElemOutTxt186 = NULL;
gslc_tsElemRef* m_pElemOutTxt250 = NULL;
gslc_tsElemRef* m_pElemOutTxt250_251 = NULL;
gslc_tsElemRef* m_pElemOutTxt250_252 = NULL;
gslc_tsElemRef* m_pElemOutTxt259_261 = NULL;
gslc_tsElemRef* m_pElemPF0 = NULL;
gslc_tsElemRef* m_pElemPF1 = NULL;
gslc_tsElemRef* m_pElemPF2 = NULL;
gslc_tsElemRef* m_pElemPF3 = NULL;
gslc_tsElemRef* m_pElemPSKConf229_233 = NULL;
gslc_tsElemRef* m_pElemPrevPage = NULL;
gslc_tsElemRef* m_pElemProgress1 = NULL;
gslc_tsElemRef* m_pElemRBFreqSrc = NULL;
gslc_tsElemRef* m_pElemRBRadioButton2_4 = NULL;
gslc_tsElemRef* m_pElemRBRadioButton3 = NULL;
gslc_tsElemRef* m_pElemREFunit = NULL;
gslc_tsElemRef* m_pElemRemFreq = NULL;
gslc_tsElemRef* m_pElemSSIDConf227_231 = NULL;
gslc_tsElemRef* m_pElemSWRSetting = NULL;
gslc_tsElemRef* m_pElemSWRSetting154 = NULL;
gslc_tsElemRef* m_pElemSeekbarRMS = NULL;
gslc_tsElemRef* m_pElemSeekbarSPEED = NULL;
gslc_tsElemRef* m_pElemSeekbarSTALL = NULL;
gslc_tsElemRef* m_pElemSigSrc146 = NULL;
gslc_tsElemRef* m_pElemSliderBand = NULL;
gslc_tsElemRef* m_pElemSwitchFreq = NULL;
gslc_tsElemRef* m_pElemTRXOK = NULL;
gslc_tsElemRef* m_pElemTipInfo = NULL;
gslc_tsElemRef* m_pElemVal17_18_24 = NULL;
gslc_tsElemRef* m_pElemVal17_19_25 = NULL;
gslc_tsElemRef* m_pElemVal17_20_26 = NULL;
gslc_tsElemRef* m_pElemVal17_23 = NULL;
gslc_tsElemRef* m_pElemValBFO0 = NULL;
gslc_tsElemRef* m_pElemValBFO1 = NULL;
gslc_tsElemRef* m_pElemValBFO2 = NULL;
gslc_tsElemRef* m_pElemValFS0 = NULL;
gslc_tsElemRef* m_pElemValFSE = NULL;
gslc_tsElemRef* m_pElemValFStep = NULL;
gslc_tsElemRef* m_pElemValFreq = NULL;
gslc_tsElemRef* m_pElemWiFiSave = NULL;
gslc_tsElemRef* m_pElemXRingGauge1 = NULL;
gslc_tsElemRef* m_pElem_ICOM_Addr8 = NULL;
gslc_tsElemRef* m_pElem_MaxPos = NULL;
gslc_tsElemRef* m_pElem_MotorPos = NULL;
gslc_tsElemRef* m_pElem_MotorPos213 = NULL;
gslc_tsElemRef* m_pElem_SSID0 = NULL;
gslc_tsElemRef* m_pElem_TrxName = NULL;
gslc_tsElemRef* m_pElemtxtPSK = NULL;
gslc_tsElemRef* m_pListSlider1 = NULL;
gslc_tsElemRef* m_pListSlider2 = NULL;
gslc_tsElemRef* m_pListSlider4 = NULL;
gslc_tsElemRef* p_ElemSteps = NULL;
gslc_tsElemRef* p_ElemStepsCur = NULL;
gslc_tsElemRef* p_Elem_InputString = NULL;
gslc_tsElemRef* p_Elem_Unit = NULL;
gslc_tsElemRef* p_elem_IP_addr165_179_188 = NULL;
gslc_tsElemRef* p_elem_IP_addr165_183 = NULL;
gslc_tsElemRef* m_pElemKeyPadNum = NULL;
gslc_tsElemRef* m_pElemKeyPadAlpha = NULL;
//<Save_References !End!>

// Define debug message function
static int16_t DebugOut(char ch) {
  if (ch == (char)'\n') Serial.println("");
  else Serial.write(ch);
  return 0;
}

//uint16_t last_act_page=E_PG_MAIN;

HARD_CONFIG_DATA mlat_cfg_data;
SYSTEM_CFG mlat_act_setting;

void resprintf(char* format, ...) {
  char resp[MAX_STR];
  va_list aptr;
  va_start(aptr, format);
  vsprintf(resp, format, aptr);
  va_end(aptr);
  if (TelnetConnected) telnet.print(resp);
  Serial.print(resp);
}

void EnableButton(gslc_tsElemRef* Button, gslc_tsColor color = GSLC_COL_RED) {
  gslc_ElemSetClickEn(&m_gui, Button, true);
  gslc_ElemSetCol(&m_gui, Button, GSLC_COL_BLUE_DK2, color, GSLC_COL_BLUE_DK1);
}
void DisableButton(gslc_tsElemRef* Button) {
  gslc_ElemSetClickEn(&m_gui, Button, false);
  gslc_ElemSetCol(&m_gui, Button, GSLC_COL_BLUE_DK2, GSLC_COL_GRAY_DK1, GSLC_COL_BLUE_DK1);
}
void SetCtrlValueInt(gslc_tsElemRef* Ctl, int32_t V) {
  char acTxt[10];
  sprintf(acTxt, "%d", V);
  gslc_ElemSetTxtStr(&m_gui, Ctl, acTxt);
}
int32_t GetCtrlValueInt(gslc_tsElemRef* Ctl) {
  return atoi(gslc_ElemGetTxtStr(&m_gui, Ctl));
}
void RemovePresetFreq() {
  if (FreqSelected >= 0) {
    char acTxt[MAX_STR];
    uint32_t freq;
    gslc_ElemXListboxGetItem(&m_gui, m_pElemListboxFreq, FreqSelected, acTxt, MAX_STR);
    freq = atof(acTxt) * 1e6;

    ML_ANT[mlat_act_setting.last_actived_ant].RemovePosition(freq);
    // gslc_ElemXListboxDeleteItemAt(&m_gui, m_pElemListboxFreq,FreqSelected);
    //SetUICommand("loadant");
    LoadAntennaDataOnUI(mlat_act_setting.last_actived_ant);
    // gslc_ElemXListboxDeleteItemAt(&m_gui, m_pElemListboxFreq,FreqSelected);
  }
}
void UpdateKeypadInput(uint8_t keyIndex) {
  char sBuffer[30];
  char tmp[2];
  char sUnit[10];
  uint16_t l;
  float f_coeff = 1;
  uint32_t targetfreq;
  memset(sBuffer, 0, 30);
  memset(tmp, 0, 2);
  sprintf(sBuffer, "%s", gslc_ElemGetTxtStr(&m_gui, p_Elem_InputString));
  sprintf(sUnit, "%s", gslc_ElemGetTxtStr(&m_gui, p_Elem_Unit));
  if (strcmp(sUnit, "MHz") == 0) {
    f_coeff = 1e6;
  } else if (strcmp(sUnit, "KHz") == 0) {
    f_coeff = 1e3;
  }

  l = strlen(sBuffer);
  switch (keyIndex) {
    case 0 ... 9:
      sprintf(tmp, "%d", keyIndex);
      strcat(sBuffer, tmp);
      gslc_ElemSetTxtStr(&m_gui, p_Elem_InputString, sBuffer);
      break;
    case 10:
      if (strstr(sBuffer, ".")) return;
      strcat(sBuffer, ".");
      gslc_ElemSetTxtStr(&m_gui, p_Elem_InputString, sBuffer);
      break;
    case 11:
      //<-
      if (l) memset(sBuffer + l - 1, 0, 1);
      gslc_ElemSetTxtStr(&m_gui, p_Elem_InputString, sBuffer);
      break;
    case 12:
      //clear all
      gslc_ElemSetTxtStr(&m_gui, p_Elem_InputString, "");
      break;
    case 13:
      targetfreq = atof(sBuffer) * f_coeff;
      if (targetfreq > 0) {
        if (ML_ANT[mlat_act_setting.last_actived_ant].GetSavePositionFromFrequency(targetfreq) == -1) {
          Serial.printf("user set frequency to %d \r\n", targetfreq);
          SetUICommand("fswr %d", targetfreq);
        } else {
          Serial.printf("Frequency %d is already set\r\n", targetfreq);
        }
      }
      PageHide(E_PG_NUMKEYPAD);
      break;
    case 14:
      gslc_ElemSetTxtStr(&m_gui, p_Elem_Unit, "MHz");
      break;
    case 15:
      gslc_ElemSetTxtStr(&m_gui, p_Elem_Unit, "KHz");
      break;
    case 16:
      gslc_ElemSetTxtStr(&m_gui, p_Elem_Unit, "Hz");
      break;
  };
  return;
}

// ------------------------------------------------
// Callback Methods
// ------------------------------------------------
bool CbBtnCommon(void* pvGui, void* pvElemRef, gslc_teTouch eTouch, int16_t nX, int16_t nY) {
  // Typecast the parameters to match the GUI and element types
  gslc_tsGui* pGui = (gslc_tsGui*)(pvGui);
  gslc_tsElemRef* pElemRef = (gslc_tsElemRef*)(pvElemRef);
  gslc_tsElem* pElem = gslc_GetElemFromRef(pGui, pElemRef);
  char acTxt[MAX_STR];
   //  Serial.printf("%d> pressed\r\n",pElem->nId);

  if (eTouch == GSLC_TOUCH_UP_IN) {
    // From the element's ID we can determine which button was pressed.

    switch (pElem->nId) {
        //<Button Enums !Start!>
      case E_ELEM_BTN118:
        PageShow(E_PG_MENU);
        break;
      case E_ELEM_BTN119:
        ProcessPresetButton(0);
        break;
      case E_ELEM_BTN120:
        ProcessPresetButton(1);
        break;
      case E_ELEM_BTN121:
        ProcessPresetButton(2);
        break;
      case E_ELEM_BTN122:
        ProcessPresetButton(3);
        break;
      case E_ELEM_BTN123:
        break;
      case E_ELEM_BTN124:
        break;  
      case E_ELEM_BTN156:       // pos ++
         SetUICommand("move 1 800");
        break;
      case E_ELEM_BTN155:       // pos --
 
         SetUICommand("move -1 800");
        break;
      case E_ELEM_BTN_LINKTEST:

        break;
      case E_ELEM_BTN_TRXOK:
        PageHide(E_PG_RADIO);
        //save Selected TRX...
        if (TrxSelected >= 0) {
          mlat_act_setting.LastSelectedTRX = (SUPPORTED_TRX_TYPE)TrxSelected;
          mlat_act_setting.TrxAddress = atoi(gslc_ElemGetTxtStr(&m_gui, m_pElem_ICOM_Addr8));
          Serial.printf("will save Trx to %d, addr:%d\r\n", mlat_act_setting.LastSelectedTRX, mlat_act_setting.TrxAddress);
          SaveCommonConfiguration();

        } else {
          Serial.printf("no valid TRX selected.\r\n");
        }

        break;
      case E_ELEM_NUMINPUT8:
        // Clicked on edit field, so show popup box and associate with this text field
        gslc_ElemXKeyPadInputAsk(&m_gui, m_pElemKeyPadNum, E_POP_KEYPAD_NUM, m_pElem_ICOM_Addr8);
        break;
      case E_ELEM_BTN64:
        PageHide(E_PG_ANT);
        break;
      case E_ELEM_BTN69:
        PageHide(E_PG_RADIO);
        break;
      case E_ELEM_BTN70:
        PageHide(E_PG_MENU);
        break;
      case E_ELEM_BTN66:
        PageHide(E_PG_SWR_CHART);
        SwrMeterMode = false;
        
        break;

      case E_ELEM_MSG_OK:
         MsgBoxOK=true;
        PageHide(E_PG_MSBOX);
        //MsgOK
        break;
      case E_ELEM_BTN_SWITCH_ANT:
        // gslc_SetPageCur(&m_gui, E_PG_MAIN);

        break;
      case E_ELEM_BTN54:  //Add freq
        PageShow(E_PG_NUMKEYPAD);
        break;
      case E_ELEM_BTN55:  //remove freq
        RemovePresetFreq();
        break;
      case E_ELEM_BTN56:  //page ant 1
        break;
      case E_ELEM_BTN57:  //page ant 2
        break;
      case E_ELEM_BTN58:  //page ant 3
        break;
      case E_ELEM_BTN72:
        PageShow(E_PG_WIFI);
        break;
      case E_ELEM_BTN115:
        PageShow(E_PG_RADIO);
        break;
      case E_ELEM_BTN116:
        PageShow(E_PG_ANT);
        break;
      case E_ELEM_BTN125:
        PageShow(E_PG_SWR_CHART);
        break;
      case E_ELEM_BTN129:
        DoOTAUpgrade();
        break;
      case E_ELEM_BTN114:
        SwrMeterMode = false;
        PageShow(E_PG_POPUP_FS);
        break;
      case E_ELEM_TEXTINPUT2:
        // Clicked on edit field, so show popup box and associate with this text field
        gslc_ElemXKeyPadInputAsk(&m_gui, m_pElemKeyPadAlpha, E_POP_KEYPAD_ALPHA, m_pElemtxtPSK);
        break;
      case E_ELEM_BTN74:
        PageHide(E_PG_WIFI);
        break;
      case E_ELEM_BTN113:  //refresh wifi
        RefreshWifiList();
        break;
      case E_ELEM_BTN128:  //E_ELEM_BTN128
        //save Wifi.
        //mlat_act_setting.WifiSSID
        //m_pElemtxtPSK
        SaveWifi();
        break;
      case E_ELEM_BTN_NUM1:
        UpdateKeypadInput(1);
        break;
      case E_ELEM_BTN_NUM2:
        UpdateKeypadInput(2);
        break;
      case E_ELEM_BTN_NUM3:
        UpdateKeypadInput(3);
        break;
      case E_ELEM_BTN_NUM4:
        UpdateKeypadInput(4);
        break;
      case E_ELEM_BTN_NUM5:
        UpdateKeypadInput(5);
        break;
      case E_ELEM_BTN_NUM6:
        UpdateKeypadInput(6);
        break;
      case E_ELEM_BTN_NUM7:
        UpdateKeypadInput(7);
        break;
      case E_ELEM_BTN_NUM8:
        UpdateKeypadInput(8);
        break;
      case E_ELEM_BTN_NUM9:
        UpdateKeypadInput(9);
        break;
      case E_ELEM_BTN_NUMDOT:
        UpdateKeypadInput(10);
        break;
      case E_ELEM_BTN_NUM0:
        UpdateKeypadInput(0);
        break;
      case E_ELEM_BTN_MHZ:
        UpdateKeypadInput(14);
        break;
      case E_ELEM_BTN_BKSP:
        UpdateKeypadInput(11);
        break;
      case E_ELEM_BTN_ENT:
        UpdateKeypadInput(13);
        break;
      case E_ELEM_BTN_CLR:
        UpdateKeypadInput(12);
        break;
      case E_ELEM_BTN112:
        PageHide(E_PG_NUMKEYPAD);
        break;
      case E_ELEM_BTN_FREQOK:
        //get fs, fe, fstep,
        Config2SwrMode();
        PageHide(E_PG_POPUP_FS);
        break;
      case E_ELEM_NUMINPUT11:
        // Clicked on edit field, so show popup box and associate with this text field
        gslc_ElemXKeyPadInputAsk(&m_gui, m_pElemKeyPadNum, E_POP_KEYPAD_NUM, m_pElemValFS0);
        break;
      case E_ELEM_NUMINPUT12:
        // Clicked on edit field, so show popup box and associate with this text field
        gslc_ElemXKeyPadInputAsk(&m_gui, m_pElemKeyPadNum, E_POP_KEYPAD_NUM, m_pElemValFSE);
        break;
      case E_ELEM_NUMINPUT13:
        // Clicked on edit field, so show popup box and associate with this text field
        gslc_ElemXKeyPadInputAsk(&m_gui, m_pElemKeyPadNum, E_POP_KEYPAD_NUM, m_pElemValFStep);
        break;
      case E_ELEM_BTN133:
        PageHide(E_PG_MOTOR_CFG);
        break;
      case E_ELEM_BTN131:
        PageShow(E_PG_MOTOR_CFG);
        break;
      case E_ELEM_BTN65:
        //Find Home...
        SetUICommand("findhome");
        break;
      case E_ELEM_BTN134:
        //Save Motor Parameters.
        MotorInformationDef motinf;
        ML_ANT[mlat_act_setting.last_actived_ant].GetMotorParameters(&motinf);
        motinf.MaxCurrent = gslc_ElemXSeekbarGetPos(&m_gui, m_pElemSeekbarRMS);
        motinf.min_delay_us = gslc_ElemXSeekbarGetPos(&m_gui, m_pElemSeekbarSPEED);
        motinf.StallTH = gslc_ElemXSeekbarGetPos(&m_gui, m_pElemSeekbarSTALL);
        ML_ANT[mlat_act_setting.last_actived_ant].SaveMotorParameters(&motinf);
        break;
      case E_ELEM_BTN135:
        gslc_ElemXSeekbarSetPos(&m_gui, m_pElemSeekbarRMS, DEFAULT_MOTOR_CURRENT);
        gslc_ElemXSeekbarSetPos(&m_gui, m_pElemSeekbarSPEED, DEFAULT_MOTOT_INT_TIME);
        gslc_ElemXSeekbarSetPos(&m_gui, m_pElemSeekbarSTALL, DEFAULT_MOTOR_STALL_TH);
        break;
      case E_ELEM_BTN136:  //BFO Ctrl
        PageShow(E_PG_BFO);
        break;
      case E_ELEM_BTN137:  //Save Basic setting...
        break;
      case E_ELEM_BTN138:
        PageHide(E_PG_BASIC_SETTING);
        break;
      case E_ELEM_BTN139:
        PageShow(E_PG_BASIC_SETTING);
        break;
      case E_ELEM_NUMINPUT14:
        // Clicked on edit field, so show popup box and associate with this text field
        gslc_ElemXKeyPadInputAsk(&m_gui, m_pElemKeyPadNum, E_POP_KEYPAD_NUM, m_pElemValBFO0);
        break;
      case E_ELEM_BTN140:
        //toggle BFO OnOff
        break;
      case E_ELEM_BTN142:
        PageHide(E_PG_BFO);
        break;
      case E_ELEM_NUMINPUT15:
        // Clicked on edit field, so show popup box and associate with this text field
        gslc_ElemXKeyPadInputAsk(&m_gui, m_pElemKeyPadNum, E_POP_KEYPAD_NUM, m_pElemValBFO1);
        break;
      case E_ELEM_BTN144:
        break;
      case E_ELEM_NUMINPUT16:
        // Clicked on edit field, so show popup box and associate with this text field
        gslc_ElemXKeyPadInputAsk(&m_gui, m_pElemKeyPadNum, E_POP_KEYPAD_NUM, m_pElemValBFO2);
        break;
      case E_ELEM_BTN145:
        break;
      case E_ELEM_BTN146:
        ToggleFreqSource();
        break;
      case E_ELEM_NUMINPUT23:
        // Clicked on edit field, so show popup box and associate with this text field
        gslc_ElemXKeyPadInputAsk(&m_gui, m_pElemKeyPadNum, E_POP_KEYPAD_NUM, m_pElemVal17_23);
        break;
      case E_ELEM_NUMINPUT24:
        // Clicked on edit field, so show popup box and associate with this text field
        gslc_ElemXKeyPadInputAsk(&m_gui, m_pElemKeyPadNum, E_POP_KEYPAD_NUM, m_pElemVal17_18_24);
        break;
      case E_ELEM_NUMINPUT25:
        // Clicked on edit field, so show popup box and associate with this text field
        gslc_ElemXKeyPadInputAsk(&m_gui, m_pElemKeyPadNum, E_POP_KEYPAD_NUM, m_pElemVal17_19_25);
        break;
      case E_ELEM_NUMINPUT26:
        // Clicked on edit field, so show popup box and associate with this text field
        gslc_ElemXKeyPadInputAsk(&m_gui, m_pElemKeyPadNum, E_POP_KEYPAD_NUM, m_pElemVal17_20_26);
        break;
      case E_ELEM_BTN152:
        SaveSWRDataFromUI();
        PageHide(E_PG_SWR_CAL);  //save meter cal parameters
        break;
      case E_ELEM_BTN153:  //load meter cal parameters default.
                           // PageHide(E_PG_SWR_CAL);
        SetSwrDefault();
        LoadSWRData2UI();
        break;
      case E_ELEM_BTN154:
        LoadSWRData2UI();
        PageShow(E_PG_SWR_CAL);
        break;
        //<Button Enums !End!>
      default:
        break;
    }
  }
  return true;
}
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
void loop() {
   //theMinOfBoot=
  if (millis()-theTickOfBoot>1000)
  {
    theSecOfBoot++;    
    theTickOfBoot=millis();
    if (theSecOfBoot>60)
    {
      theSecOfBoot=0;
      theMinOfBoot++;
       ShowUpTime();
      if (theMinOfBoot>60)
      {
        theMinOfBoot=0;
        theHoursOfBoot++;
      }
    }
  } 
  if (SwrMeterMode) {
      DoFreqScanOnScreen();
  } else {
 
      UpdateFrequencyCounter();
      UpdateSWRMeter();
   }

  SerialTask();
  ProcessIOTask();
  ProcessWiFiTask();
  //RefreshBusyBox();
  //check TRX ..
  // ------------------------------------------------
  // Update GUI Elements
  // ------------------------------------------------

  //TODO - Add update code for any text, gauges, or sliders
  // ------------------------------------------------
  // Periodically call GUIslice update function
  // ------------------------------------------------
  gslc_Update(&m_gui);
}

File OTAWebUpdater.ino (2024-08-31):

#include <WiFi.h>
#include <WiFiClient.h>
#include <WebServer.h>
#include <ESPmDNS.h>
#include <Update.h>

#include "ESPTelnet.h"          
   
#include "HardwareStuff.h"
const char* host = "esp32";
extern bool TelnetEnabled;
extern bool OTAModeEnabled;
bool TelnetConnected=false;
ESPTelnet telnet;

 

WebServer server(80);
 
/*
 * Login page
 */

const char* loginIndex =
 "<form name='loginForm'>"
    "<table width='20%' bgcolor='A09F9F' align='center'>"
        "<tr>"
            "<td colspan=2>"
                "<center><font size=4><b>MLAT OTA Login Page</b></font></center>"
                "<br>"
            "</td>"
            "<br>"
            "<br>"
        "</tr>"
        "<tr>"
             "<td>Username:</td>"
             "<td><input type='text' size=25 name='userid'><br></td>"
        "</tr>"
        "<br>"
        "<br>"
        "<tr>"
            "<td>Password:</td>"
            "<td><input type='Password' size=25 name='pwd'><br></td>"
            "<br>"
            "<br>"
        "</tr>"
        "<tr>"
            "<td><input type='submit' onclick='check(this.form)' value='Login'></td>"
        "</tr>"
    "</table>"
"</form>"
"<script>"
    "function check(form)"
    "{"
    "if(form.userid.value=='admin' && form.pwd.value=='admin')"
    "{"
    "window.open('/serverIndex')"
    "}"
    "else"
    "{"
    " alert('Error Password or Username')/*displays error message*/"
    "}"
    "}"
"</script>";

/*
 * Server Index Page
 */

const char* serverIndex =
"<script src='https://cdnjs.cloudflare.com/ajax/libs/jquery/3.6.1/jquery.min.js'></script>"
"<form method='POST' action='#' enctype='multipart/form-data' id='upload_form'>"
   "<input type='file' name='update'>"
        "<input type='submit' value='Update'>"
    "</form>"
 "<div id='prg'>progress: 0%</div>"
 "<script>"
  "$('form').submit(function(e){"
  "e.preventDefault();"
  "var form = $('#upload_form')[0];"
  "var data = new FormData(form);"
  " $.ajax({"
  "url: '/update',"
  "type: 'POST',"
  "data: data,"
  "contentType: false,"
  "processData:false,"
  "xhr: function() {"
  "var xhr = new window.XMLHttpRequest();"
  "xhr.upload.addEventListener('progress', function(evt) {"
  "if (evt.lengthComputable) {"
  "var per = evt.loaded / evt.total;"
  "$('#prg').html('progress: ' + Math.round(per*100) + '%');"
  "}"
  "}, false);"
  "return xhr;"
  "},"
  "success:function(d, s) {"
  "console.log('success!')"
 "},"
 "error: function (a, b, c) {"
 "}"
 "});"
 "});"
 "</script>";

/*
 * setup function
 */
 void WifiInit()
 {
       // Set WiFi to station mode and disconnect from an AP if it was previously connected
    WiFi.mode(WIFI_STA);
    WiFi.disconnect();
 }
 int LoadOTASetting(String& ssid,String& psk)
 {
    
    return 0;
 }
int SaveOTASetting(String ssid,String psk)
{
    
    return 0;
}
void onTelnetConnect(String ip) {
  Serial.print("- Telnet: ");
  Serial.print(ip);
  Serial.println(" connected");
  
  telnet.println("\nWelcome to MLAT console: " + telnet.getIP());
  telnet.println("(Use ^] + q  to disconnect.)");
  TelnetConnected=true;
}

void onTelnetDisconnect(String ip) {
  Serial.print("- Telnet: ");
  Serial.print(ip);
  Serial.println(" disconnected");
  TelnetConnected=false;
}

void onTelnetReconnect(String ip) {
  Serial.print("- Telnet: ");
  Serial.print(ip);
  Serial.println(" reconnected");
}

void onTelnetConnectionAttempt(String ip) {
  Serial.print("- Telnet: ");
  Serial.print(ip);
  Serial.println(" tried to connected");
}

void onTelnetInput(String str) {
  // checks for a certain command
  //Serial.println(str.c_str());
  if (str == "bye") {
    telnet.println("> disconnecting you...");
    telnet.disconnectClient();
    }else
    {
      ProcessTelnetCommand(str);
    }
  }
 //  telnet.loop();
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
